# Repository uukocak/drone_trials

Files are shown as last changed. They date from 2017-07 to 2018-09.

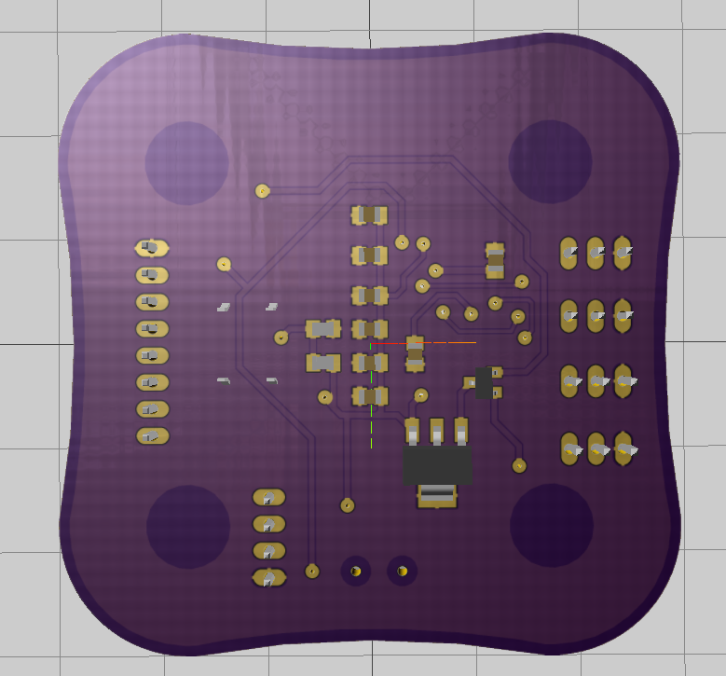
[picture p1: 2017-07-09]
board_design/render_w1/bot.png

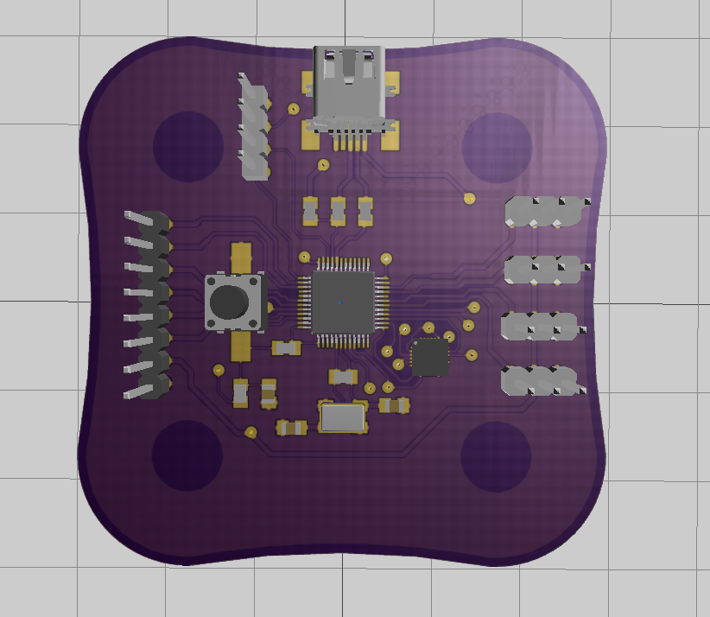
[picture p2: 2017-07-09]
board_design/render_w1/top.png

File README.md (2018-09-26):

# Unnamed Drone Project

Openpilot inspired personal drone project. It is a hobby project with no future expectations.

## Current Progress

### Board Design
  - Design made using OpenPilot CC3D board schematic with little component changes.
  - First prototype builted and will be tested.
### Mechanical Design
  - A small drone body sketched and designed on Solidworks 
  - Mechanical prototype 3D printed.
### Software Development
  - Pending...

Check the orginal OpenPilot project at  :
- https://github.com/librepilot
- https://opwiki.readthedocs.io/en/latest/index.html

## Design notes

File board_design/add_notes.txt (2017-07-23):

BOARD MUST BE UPDATED 
-Top and Bottom GND planes must be connected 
-On Bottom , GND plane inside the power lanes must be connected to other GND planes

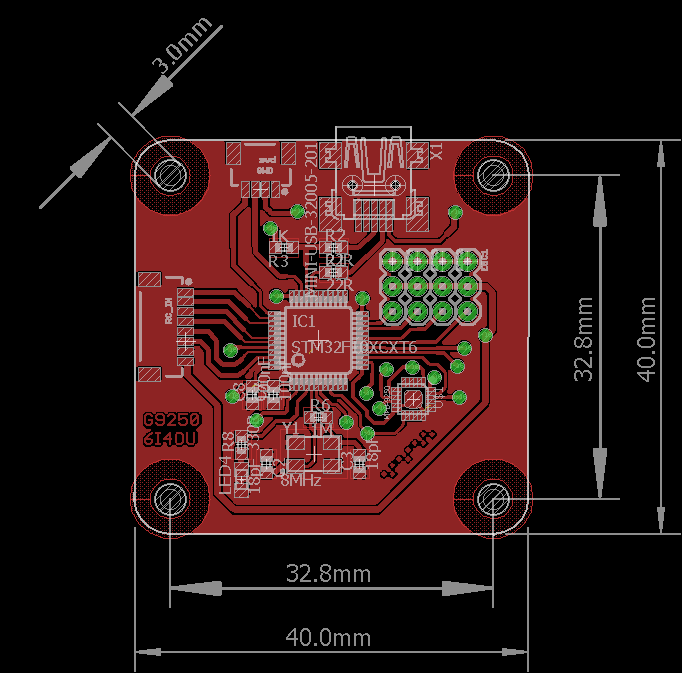
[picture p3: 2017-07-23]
board_design/render_w1s1/top_doc.png

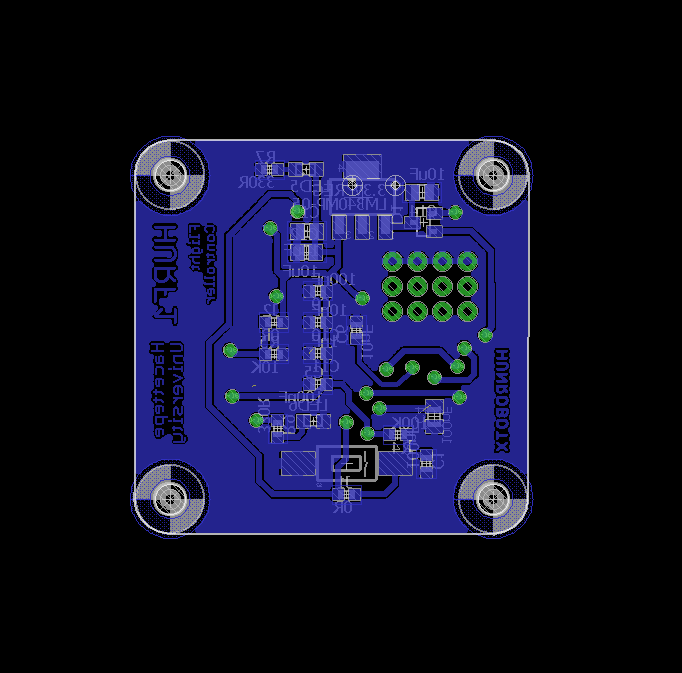
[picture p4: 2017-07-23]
board_design/render_w1s1/bot_doc.png

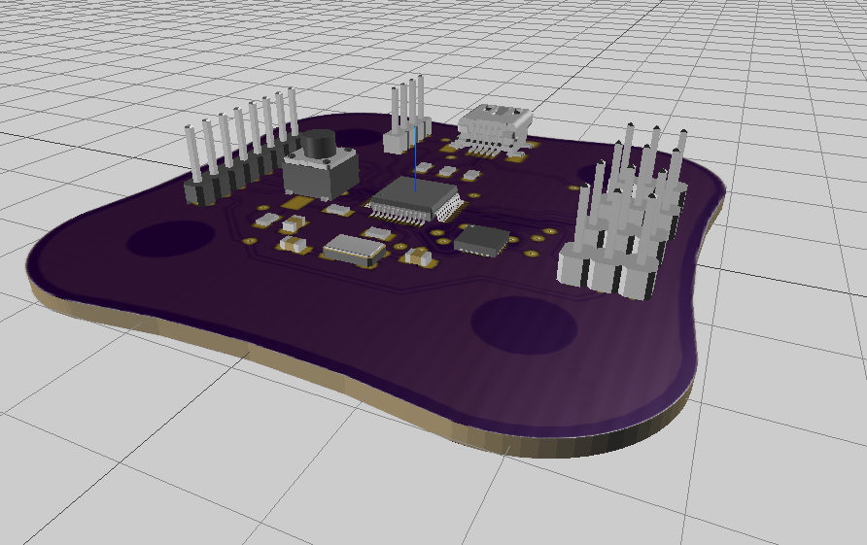
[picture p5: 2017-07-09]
board_design/render_w1/iso2.png

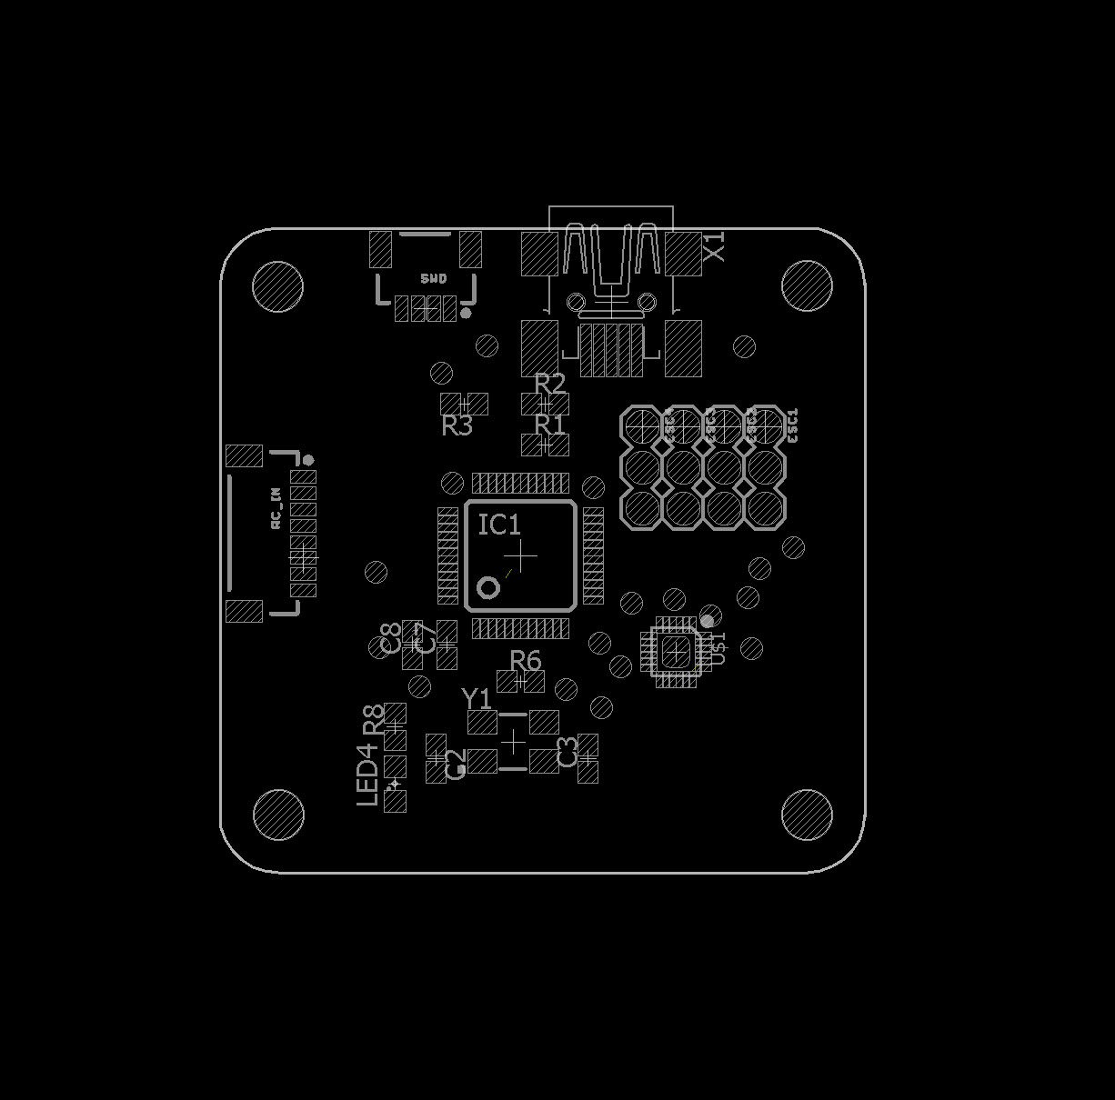
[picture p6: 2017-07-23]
board_design/render_w1s1/top_place.png

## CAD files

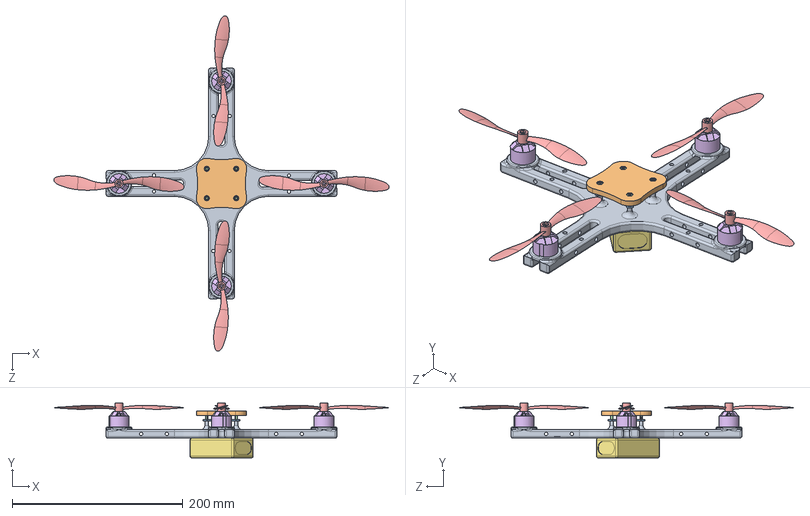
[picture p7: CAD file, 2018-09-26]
mechanical_design/SolidworksParts/Assembly1.SLDASM
392.2 x 64.0 x 392.2 mm
complete_drone_body
controlboard_mount
pdb
B18.3.1M - 3 x 0.5 x 20 Hex SHCS -- 20CHX x 4
GWS 6050 Propeller x 4
motor x 4
Turnigy_1300mAh_3S_Lipo_Pack

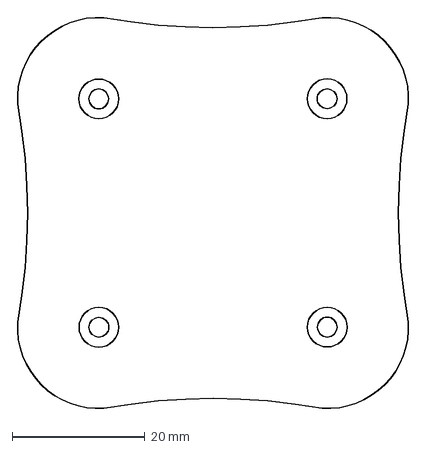
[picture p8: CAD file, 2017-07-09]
board_design/controlboard_mount_dxf.DXF
59.4 x 59.4 mm

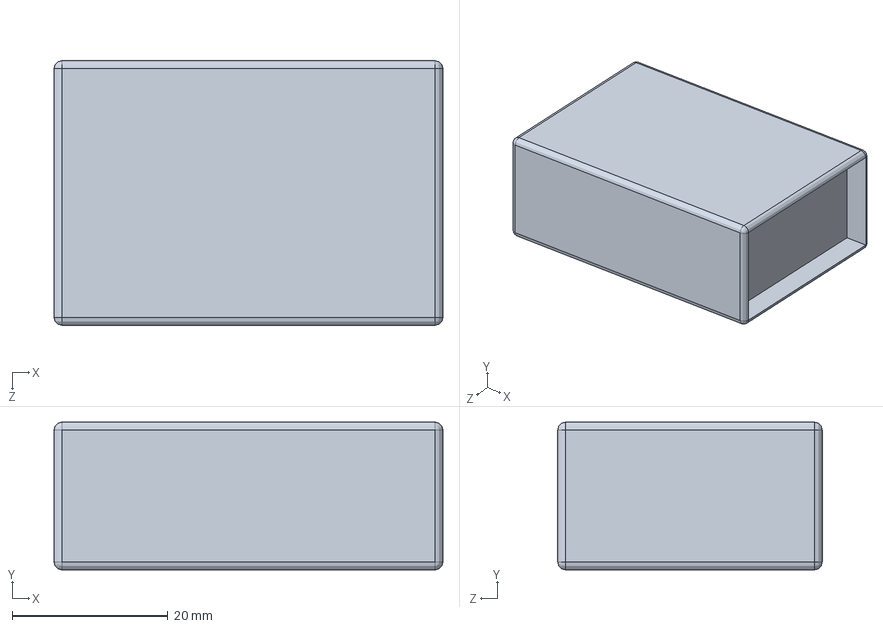
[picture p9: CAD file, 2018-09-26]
mechanical_design/SolidworksParts/PartLib/ExampleReceiver.SLDPRT
50.0 x 19.0 x 34.0 mm

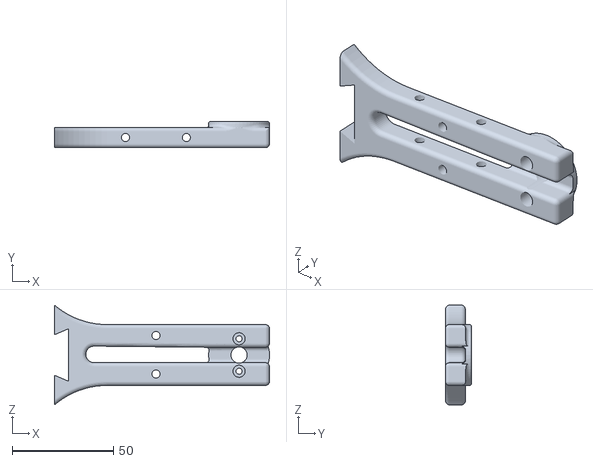
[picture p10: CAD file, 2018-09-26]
mechanical_design/STL/Drone_v3_arm.STL
106.0 x 13.0 x 49.2

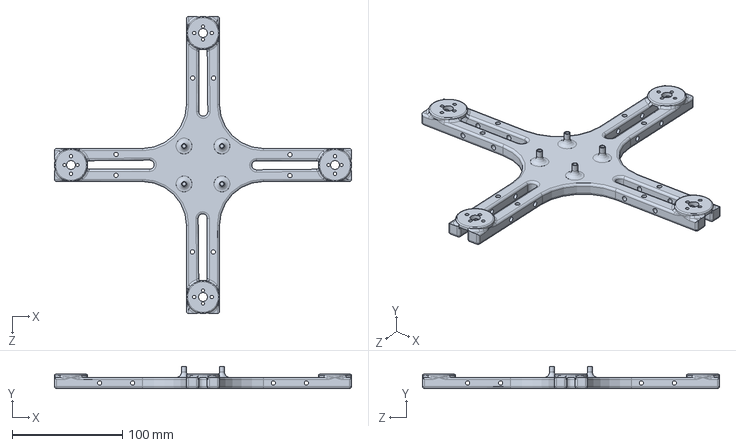
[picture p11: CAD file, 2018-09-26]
mechanical_design/SolidworksParts/MonolithDroneBody.SLDPRT
270.0 x 20.0 x 270.0 mm

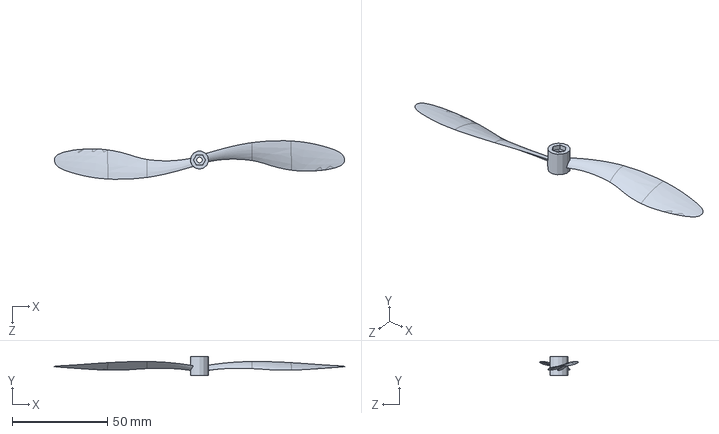
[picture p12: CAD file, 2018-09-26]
mechanical_design/SolidworksParts/PartLib/GWS 6050 Propeller.SLDPRT
152.4 x 10.0 x 20.3 mm

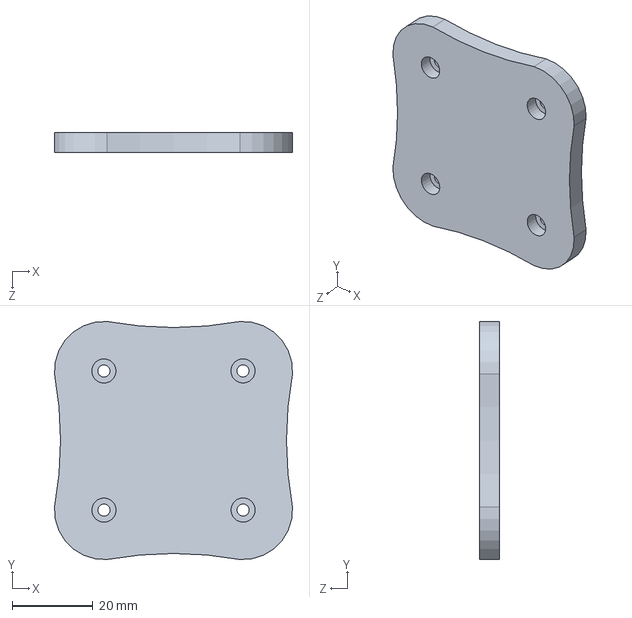
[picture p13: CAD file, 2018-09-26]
mechanical_design/SolidworksParts/ControlboardMount.SLDPRT
59.0 x 59.0 x 5.00 mm

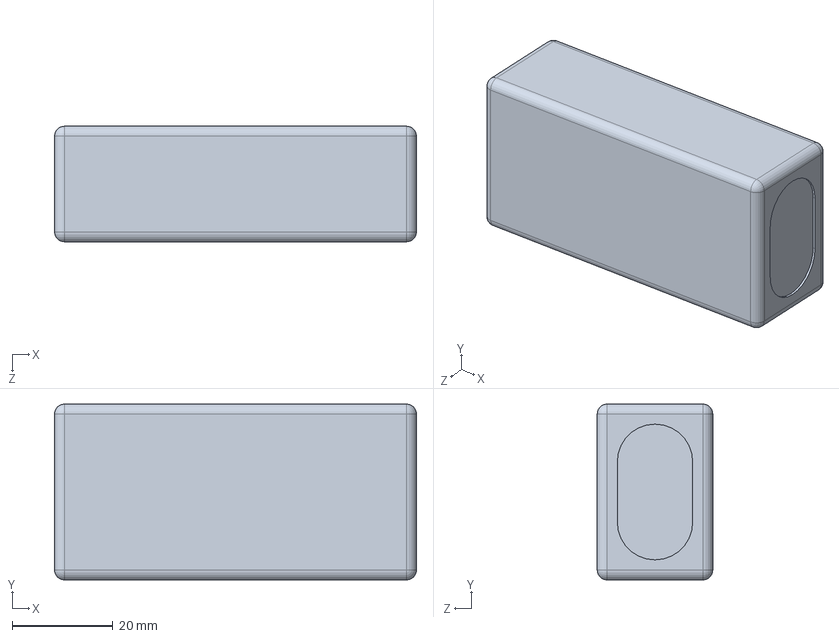
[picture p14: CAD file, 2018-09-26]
mechanical_design/SolidworksParts/PartLib/Turnigy_Lipo_Pack.SLDPRT
72.0 x 35.0 x 23.0 mm

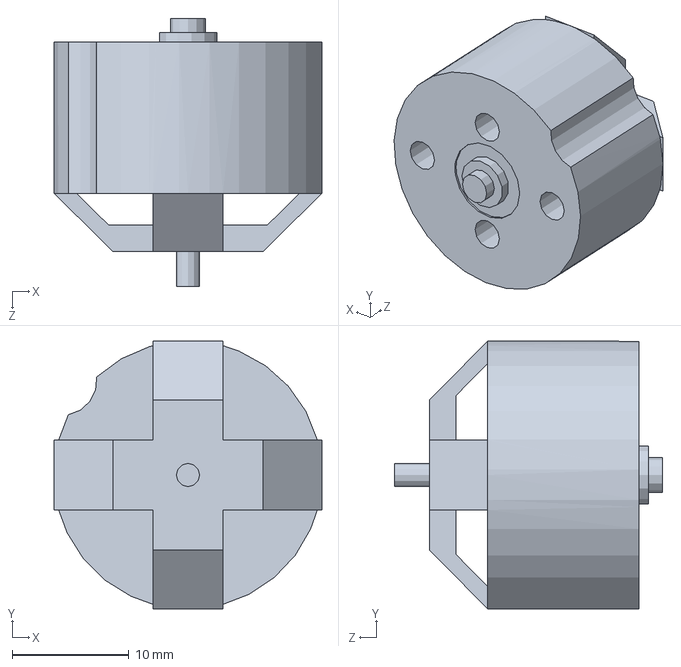
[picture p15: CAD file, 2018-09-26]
mechanical_design/SolidworksParts/PartLib/Motor.SLDPRT
23.0 x 23.0 x 23.0 mm

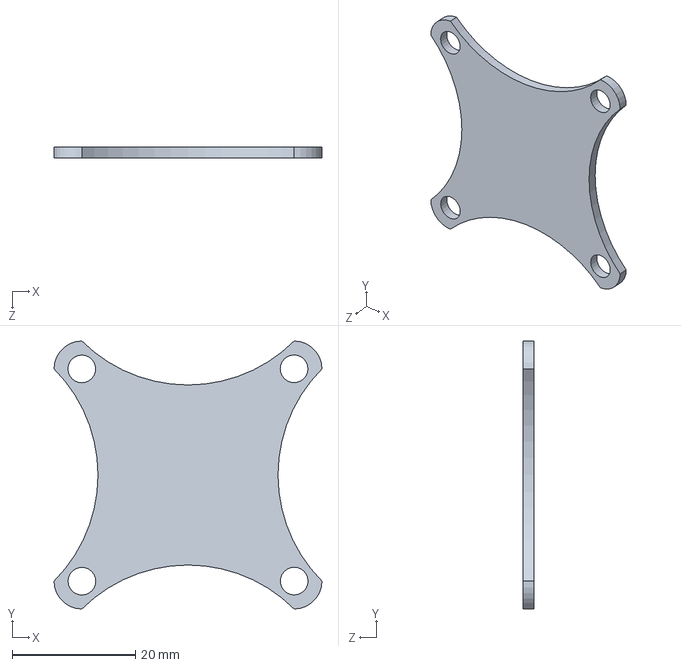
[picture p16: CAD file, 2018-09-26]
mechanical_design/SolidworksParts/PowerDistrubitionBoard.SLDPRT
43.5 x 43.5 x 1.80 mm

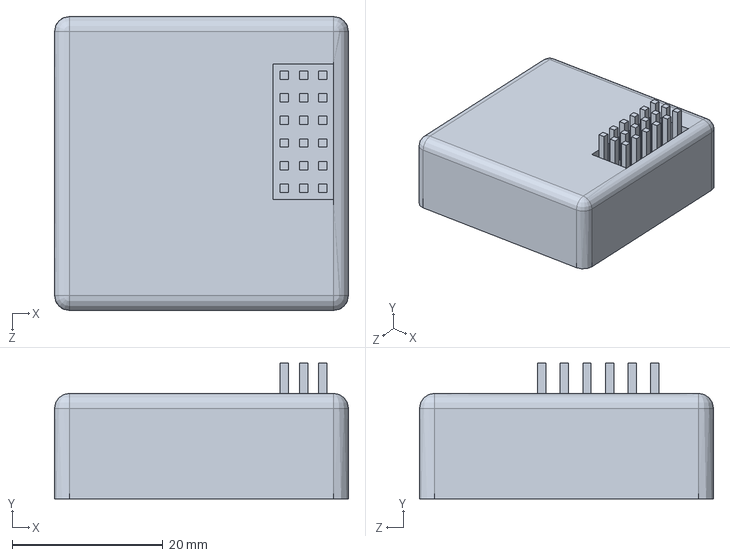
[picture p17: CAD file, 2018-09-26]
mechanical_design/SolidworksParts/PartLib/CC3Dopenpilot.SLDPRT
39.0 x 18.0 x 39.0 mm

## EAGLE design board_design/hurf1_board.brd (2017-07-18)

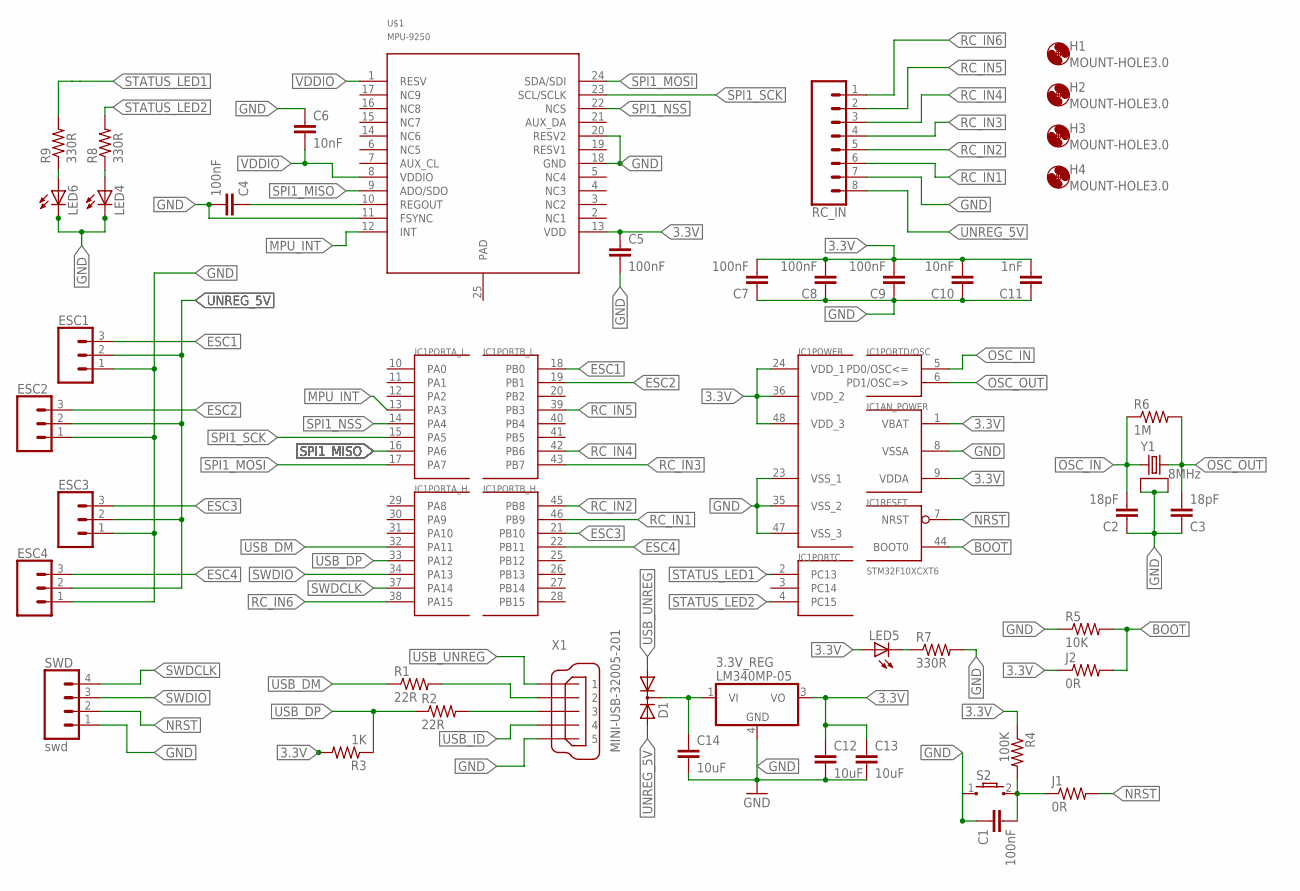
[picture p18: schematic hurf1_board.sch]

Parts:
3.3V_REG: LM340MP-05; SOT223
C1, C5, C7, C8, C9: 100nF; C0603
C2, C3: 18pF; C0603
C4: 100nF; C0805K
C6, C10: 10nF; C0603
C11: 1nF; C0603
C12, C13, C14: 10uF; C0805
D1: SOT23
ESC1, ESC2, ESC3, ESC4: CONN_03; 1X03
H1, H2, H3, H4: MOUNT-HOLE3.0; 3,0
IC1: STM32F10XCXT6; TQFP48
J1, J2: 0R; R0603
LED4, LED5, LED6: LEDSML0805; SML0805
R1, R2: 22R; R0603
R3: 1K; R0603
R4: 100K; R0603
R5: 10K; R0603
R6: 1M; R0603
R7, R8, R9: 330R; R0603
RC_IN: CONN_08; 1X08_1MM_RA
S2: TL3302_GULL_WING
SWD: swd; 1X04_1MM_RA
U$1: MPU-9250; LEAD-QFN24
X1: MINI-USB-32005-201; 32005-201
Y1: 8MHz; GSX-531

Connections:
3.3V: 3.3V_REG.3 (VO), C5.1, C7.2, C8.2, C9.2, C10.2, C11.2, C12.1, C13.1, IC1.1 (VBAT), IC1.9 (VDDA), IC1.24 (VDD_1), IC1.36 (VDD_2), IC1.48 (VDD_3), J2.1, LED5.A, R3.2, R4.1, U$1.13 (VDD)
BOOT: IC1.44 (BOOT0), J2.2, R5.2
ESC1: ESC1.3, IC1.18 (PB0)
ESC2: ESC2.3, IC1.19 (PB1)
ESC3: ESC3.3, IC1.21 (PB10)
ESC4: ESC4.3, IC1.22 (PB11)
GND: 3.3V_REG.4 (GND), C1.1, C2.1, C3.1, C4.2, C5.2, C6.1, C7.1, C8.1, C9.1, C10.1, C11.1, C12.2, C13.2, C14.2, ESC1.1, ESC2.1, ESC3.1, ESC4.1, IC1.8 (VSSA), IC1.23 (VSS_1), IC1.35 (VSS_2), IC1.47 (VSS_3), LED4.C, LED6.C, R5.1, R7.2, RC_IN.7, S2.1, SWD.1, U$1.11 (FSYNC), U$1.18 (GND), U$1.20 (RESV2), X1.5, Y1.2, Y1.4
MPU_INT: IC1.13 (PA3), U$1.12 (INT)
unnamed: R1.2, X1.2
unnamed: R2.2, X1.3
unnamed: C4.1, U$1.10 (REGOUT)
unnamed: 3.3V_REG.1 (VI), C14.1, D1.3 (C)
unnamed: C1.2, J1.1, R4.2, S2.2
unnamed: LED6.A, R9.1
unnamed: LED5.C, R7.1
unnamed: LED4.A, R8.1
NRST: IC1.7 (NRST), J1.2, SWD.2
OSC_IN: C2.2, IC1.5 (PD0/OSC<=), R6.1, Y1.1
OSC_OUT: C3.2, IC1.6 (PD1/OSC=>), R6.2, Y1.3
RC_IN1: IC1.46 (PB9), RC_IN.6
RC_IN2: IC1.45 (PB8), RC_IN.5
RC_IN3: IC1.43 (PB7), RC_IN.4
RC_IN4: IC1.42 (PB6), RC_IN.3
RC_IN5: IC1.39 (PB3), RC_IN.2
RC_IN6: IC1.38 (PA15), RC_IN.1
SPI1_MISO: IC1.16 (PA6), U$1.9 (ADO/SDO)
SPI1_MOSI: IC1.17 (PA7), U$1.24 (SDA/SDI)
SPI1_NSS: IC1.14 (PA4), U$1.22 (NCS)
SPI1_SCK: IC1.15 (PA5), U$1.23 (SCL/SCLK)
STATUS_LED1: IC1.2 (PC13), R9.2
STATUS_LED2: IC1.4 (PC15), R8.2
SWDCLK: IC1.37 (PA14), SWD.4
SWDIO: IC1.34 (PA13), SWD.3
UNREG_5V: D1.2 (A2), ESC1.2, ESC2.2, ESC3.2, ESC4.2, RC_IN.8
USB_DM: IC1.32 (PA11), R1.1
USB_DP: IC1.33 (PA12), R2.1, R3.1
USB_ID: X1.4
USB_UNREG: D1.1 (A1), X1.1
VDDIO: C6.2, U$1.1 (RESV), U$1.8 (VDDIO)

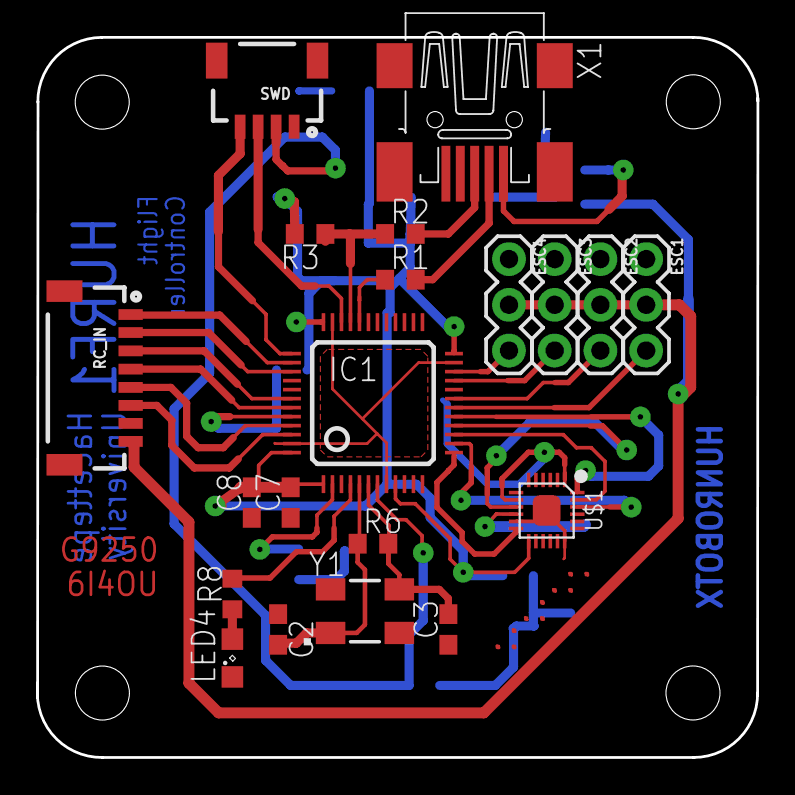
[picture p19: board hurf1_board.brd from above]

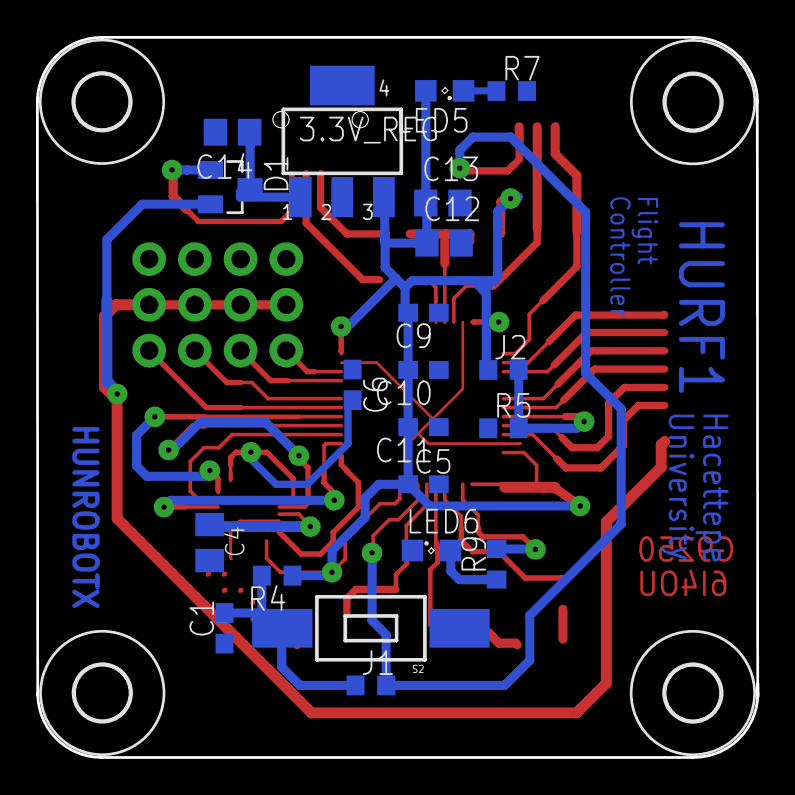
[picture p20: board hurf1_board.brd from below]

Board: 2 copper layers, 40.0 x 40.0 mm, 45 parts (25 on the bottom side), 38 nets.

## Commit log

2016-12-18 Resource Folder Created
    RESOURCE:Added STM32F103C8T6 datasheet
2017-07-05 Initial Commit -schematic added WIP -board added PRE =.gitignore added
    [hurf1_board.brd, hurf1_schematic.sch]
2017-07-09 Schematic Completed -schematic w1 -board w1 -controlboard sketch added (.dxf) =.gitignore updated = hurf1_schematic.sch -> hurf1_board.sch = board images added
    [controlboard_mount_dxf.DXF, hurf1_board.brd, hurf1_board.sch]
2017-07-13 Circuit Size Shrinked -schematic w1 (updated) -board w1s1 (updated) *SMD Package changed from 0805 -> 0603 *SWD Port changed from DIL -> JST-SH X UNREG_5V pin must be connected to diode
    [hurf1_board.brd, hurf1_board.sch]
2017-07-14 Circuit Design Updated -schematic w1(updated) *1x Power Led , 2x Status Led Added *RC_OUT and SWD packages updated -board w1s1 (updated) *All connections solved *Schematic changes applied X* RC_IN po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
    [hurf1_board.brd, hurf1_board.sch]
2017-07-15 Final touches to board -schematic w1 (updated) *RC_IN port package updated from DIL -> JST-SH -board w1s1(updated) *Schematics changes applied *General check successful *Signs and Logos added -Status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
    [hurf1_board.brd, hurf1_board.sch]
2017-07-18 Drills added , gerber out -schematic w1 (updated) -board w1s1 (updated) *Corner Mount holes added (3mm) *Board corners rounded *Signs and logos rearrenged -Status : RTF =gerber_out files added
    [hurf1_board.brd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]
2017-07-23 Documentation added =Bottom and Top component place scheme added =Schematic exported as png file =add_notes.txt added
2017-08-12 Resource Folder Updated -Dual Diode DS added -MPU9250A DS added -STM32F10xxx Ref. Man. added -SMD Crystal DS added
2018-09-26 Directory Update
    [controlboard_mount_dxf.DXF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]
2018-09-26 Mechanical Design Files
    - Sample design files for first prototype added
    - Ready to print STL files added
    [Assembly1.SLDASM, CC3Dopenpilot.SLDPRT, ControlboardMount.SLDPRT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]
2018-09-26 Mechanical Design Files
    - Readme Update
    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
    [Assembly1.SLDASM, CC3Dopenpilot.SLDPRT, ControlboardMount.SLDPRT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]

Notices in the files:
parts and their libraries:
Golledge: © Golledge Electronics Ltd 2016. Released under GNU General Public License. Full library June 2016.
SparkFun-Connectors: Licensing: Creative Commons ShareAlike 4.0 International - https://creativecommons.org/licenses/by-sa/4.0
